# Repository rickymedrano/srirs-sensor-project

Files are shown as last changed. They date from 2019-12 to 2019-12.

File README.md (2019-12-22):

<p align="center">
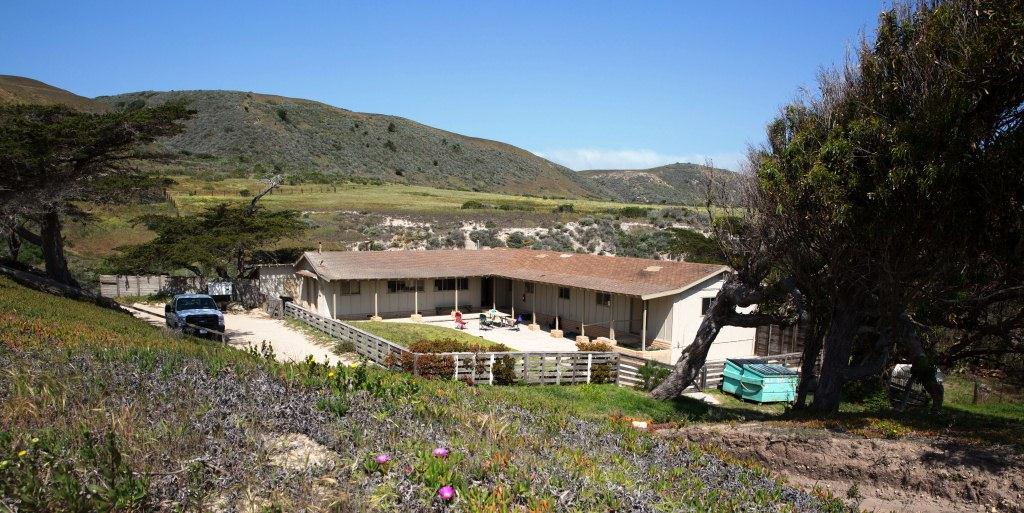
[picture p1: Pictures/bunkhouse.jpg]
Title Picture1
  <kbd></kbd>
</p>
<p align="center">
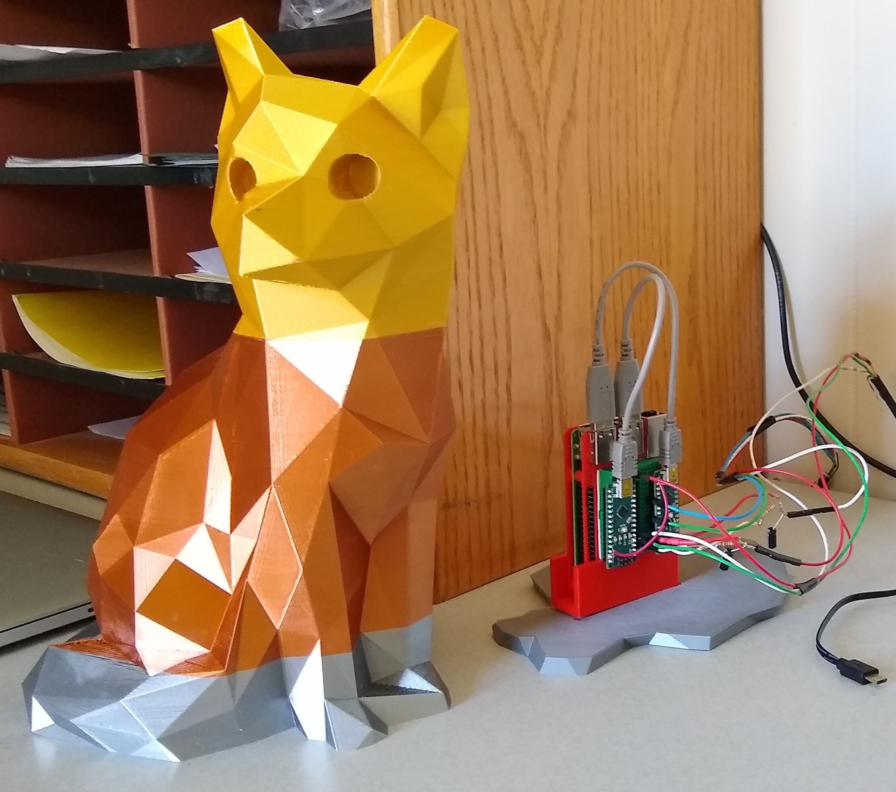
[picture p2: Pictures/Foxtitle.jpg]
Title Picture2
  <kbd></kbd>
</p>

# Overview
This project was a combination Independent Study and Capstone project for undergrad Computer Science students at CSUCI. Not wanting to design another boring app, we decided to tackle a multidisciplinary problem. Santa Rosa Island, off the coast of Southern California, is home to CSUCI's research station. The climate on the island is charaterized by mild Winters and very dry Summers. Combined with severe drought during the past decade, resources on the island are very limited. This project serves a sustainability purpose by allowing research station staff monitor in real time the resource usage of the station. It is a continuation of a project that was initially started in Dr. Wood's UNIV 492 Sustainability in Campus Infrastructure course. 

The project uses a Raspberry Pi as the main computer to read in electric and water usage, then uploads that data to an online database in the cloud. This data is now accessible on the mainland to be viewed graphically. Research station staff can now see how much and when resource usage happens and make sustainable decisions going forward. This project was then tidied up and placed into a 3D printed Island Fox, which is native to the island. 

### Experience Gained ###
* Python
* Arduino (C++)
* Microcontrollers
  * Arduino Uno & Nano
  * Analog to Digital Converter (ADC)
  * Interrupts 
  * Digital and Analog pin inputs and outputs
  * Power requirements via 5V Logic
* Electrical parameters - voltage, amperage, mains electricity, sampling, voltage dividers, resistors, capacitors
* Cloud computing: AWS
* 3D Printing and modeling: Tinkercad
* Database creation and connection, MySQL
* Project Management: Trello
* Raspbian (Linux)
  * systemd - services
  * Navigating the terminal and using bash commands
* Soldering and crimping dupont connections
* Plot.ly, Grafana, Chart-Studio, WordPress

### Program and Code Prerequisites
- Python 3 with mysql connector library
- Arduino IDE with EmonLib library
- Raspbian (we used Stretch, but Buster will work too)
- MySQL database, either locally or in the cloud. We used a MySQL RDS on AWS with their free-tier option. 
- If you want to graph the data you can use a website like Grafana and connect your database, or you can use Plotly's Chart-Studio.
- VNC on Raspbian if you want to connect to your Pi remotely.

### Hardware Prerequisites
You will need a 3D Printer if you want to print the model.
You will need a soldering iron with solder and extra wire as well. 
Here is a list of materials used in the project:

| Item  | Quantity |
| --- | --- |
| <a href="https://www.amazon.com/gp/product/B01N1LBMPG">Arduino Nano</a> | 2 |
| <a href="https://www.amazon.com/gp/product/B07BDR5PDW">Raspberry Pi 3B+</a>  | 1 |
| <a href="https://www.amazon.com/gp/product/B00MARDJZ4">Raspberry Pi Power Supply</a>  | 1 |
| <a href="https://www.amazon.com/gp/product/B073JWXGNT">32GB SD Card</a>  | 1 |
| <a href="https://www.amazon.com/gp/product/B01KKE602W">Mini Breadboard</a>  | 1 |
| <a href="https://www.amazon.com/gp/product/B003WV5DME">6'' USB to Mini USB Cable</a>  | 2 |
| <a href="https://www.amazon.com/gp/product/B01N1LBMPG">Split Core Transformer</a> | 2 |
| <a href="https://www.amazon.com/gp/product/B00X5KHD66">YF-G1 Flowmeter</a> | 2 |
| 10k Resistor | 4 |
| 10uF Capacitor | 2 |

### Getting Started
* I suggest you start here in order to understand how a CT sensor works and how the EmonLib library works https://learn.openenergymonitor.org/electricity-monitoring/ct-sensors/introduction
* You can read about systemd here https://www.raspberrypi.org/documentation/linux/usage/systemd.md
* Electrical
  * This project involves working with mains power and is therefore very dangerous. If you feel even slightly uncomfortable interacting with your breaker box, get the help of an Electrician to hook up the CT sensors. 
  * This project required two CT sensors since there were two main hot lines at the research station but most likely you'll only need 1 CT sensor if you're trying to implement this in a house.
* Water
  * Installing the flowmeter will probably require the help of a Plumber. It requires you shutting off the water main line and then installing the flowmeter inline which involves cutting pipe and testing for leaks. 
  * Your flowmeter will require a certain calibration factor to be set in the code. My calibration is most likely different than yours so you will need to test it yourself. For example, once your flowmeter is installed, you can turn on the facet and fill up a gallon jug then reference back to what the sensor is outputting, and make changes accordingly. 
* Create a free-tier AWS account and create a MySQL database https://aws.amazon.com/rds/free/

### Hardware Setup
* Water
  * Once you've installed your flowmeter, you'll need to hook it up to the Arduino Nano. There are 3 wires, 1 goes to 5V, 1 goes to Ground, 1 goes to digital pin 2 which is the interrupt pin on the Nano. We <a href="https://forum.arduino.cc/index.php?topic=8548.0" target="_blank">read</a> it was suggested to put a 10k resistor, to act as a pull up, between pin 2 and 5V but we tested this with and without the resistor and didn't notice a difference. 
  * Here is what ours looks like hooked up. Note, due to the size constraints of the breadboard, we routed the 5V connection to the other side of the breadboard, as seen by the second red wire.
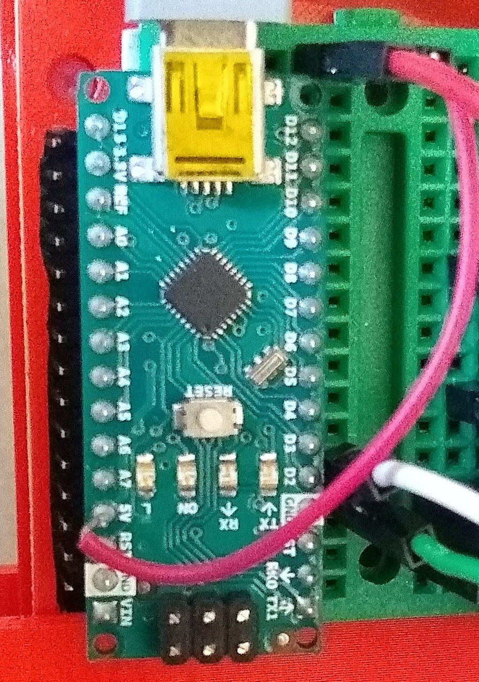
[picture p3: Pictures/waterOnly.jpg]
Water Wiring
  * 
 * Electric
   * We followed the circuit built <a href="https://learn.openenergymonitor.org/electricity-monitoring/ct-sensors/how-to-build-an-arduino-energy-monitor-measuring-current-only" target="_blank">here</a> but adapted it to be used with 2 CT sensors instead of 1. This was how we **initially**  wired up and tested with a breadboard. This set up used burden resistors and shared a 10uF capacitor to act as a low-pass filter:
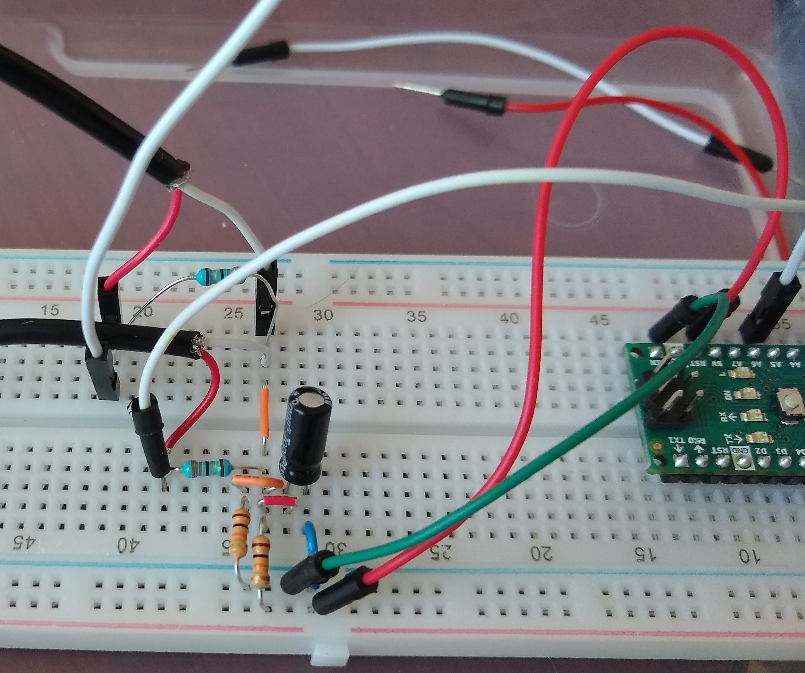
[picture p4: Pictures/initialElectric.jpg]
Initial Electric Wiring
   * 
   * We realized the CTs we had purchased, the ones linked above, had burden resistors built in. We therefore got rid of the burden resistors and added an extra 10uF capacitor that way each sensor got their own. Therefore, the final project had 2 voltage dividers, consisting of 4 10k resistors, and 2 10uF capacitors. In the picture below you can see how we soldered them together and added dupont connections. Note, one of the resistors is hidden under the shrink tubing.
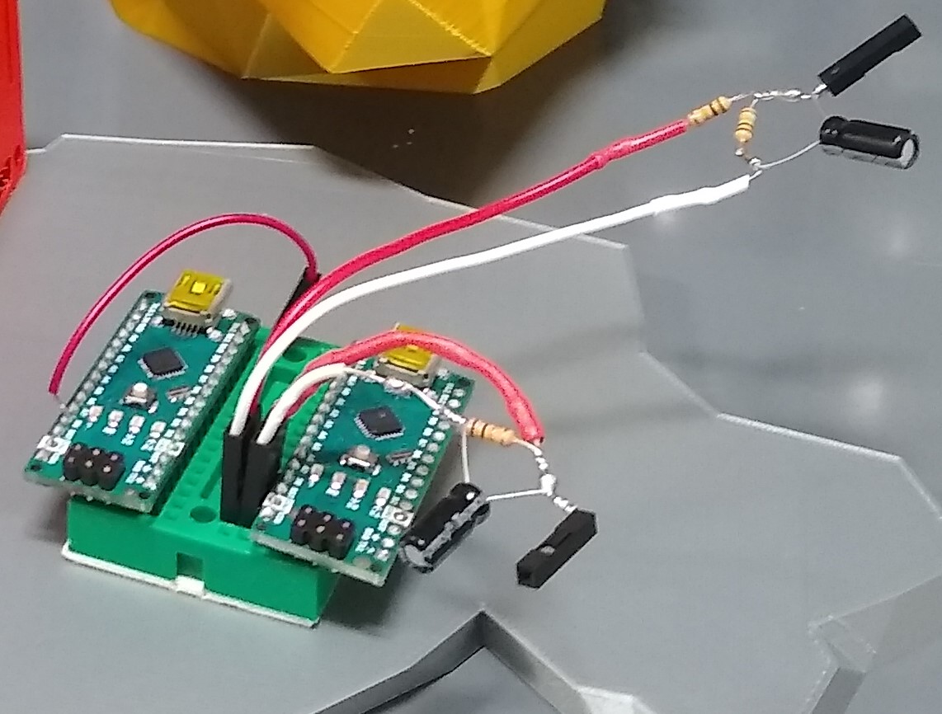
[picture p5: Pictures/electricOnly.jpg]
Electric Wiring
   * 

### The Code
* Python
  * The python scripts "powerRosa.py" and "waterRosa.py" pretty much do the exact same thing, except they upload to different tables in the database
  * Replace the endpoint address, username, and password with your own from the AWS RDS. 
  * It's better practice to save your credentails into environment variables instead of hard coding them in like we did. It worked for us as it was only a school project and the database has been moved already.
  * The reason the script starts with 
  ``` time.sleep(300) ``` is so the router had enough time to connect to the internet everytime the power came back on in the research station. If no internet connection was available, the script would exit when attempting to connect to the database. 
  * The line with ```serial.Serial('/dev/ttyUSB0',9600,timeout=1)``` will need to be modified depending how Raspbian reads in your Arduino Nano on the USB port. Somtimes it will be ACM0USB instead of ttyUSB0 or something entirely different. You can try in the terminal ```dmesg``` or ```dmesg | grep "tty"``` to verify.
* Arduino (C++)
  * Water
    * For water readings, use "yfg1Working.ino". 
    * The code is set up to take readings in mL every second, sum this over 1 minute, before outputting to the serial port, where it is ready by "waterRosa.py". 
    * Manipulate the code based on your temporal needs. I left commented print statements to assist. In your final iteration make sure you only have one print statement in the code as the Python script is only parsing 1 value over the serial port.
    * Don't use ```Serial.println()``` as it puts a new line character at the end of the output. Instead stick with ```Serial.print()``` unless you want to handle the new line character on the Python script side.
  * Electric
    * This code is meant if you're using two CT sensors. If you only plan to use 1 CT sensor, just remove the emon2 object and associates lines.
    * Like the water sensor code, this will read mA per second, sum it over 1 minute, and then output to the Serial port. 
* Raspbian
  * For the purpose of this project, our scripts needed to be started automatically anytime the Raspberry Pi started up. There are a couple options available for gettings scripts to start automatically, like with a cron job. Since systemd was introduced with Raspbian Jessie, we decided to use it. This involves creating a .service file for each script, then using systemctl to manage those service files. Here is a picture of both our services, along with their locations, and where they point to in starting our Python scripts:
  <p align="center">
    <img src="./Pictures/services.png" alt="Water Wiring" width="600"/>
  </p> 
  
* Use ```sudo systemctl start myservice.service``` to start the service, ```sudo systemctl stop myservice.service``` to stop it. Finally use ```sudo systemctl enable myservice.service``` so that it starts up on every reboot. ```sudo systemctl status myservice.service``` is also helpful in making sure things are running properly.  
* We spent much time tuning these services as they rely on many factors. If you find your service stops running, use ```journalctl``` to debug. A big issue for us was we were running the service files  with ```User=root``` but for some reason root couldnt access our mysql.connector library. Changing it to ```User=pi``` solved that issue. 

### 3D Printing
I've included all the .stl files if you want to print the fox. 
* The body requires supports and should be printed no more than 0.15mm per layer. There is some artifacting where the top of the tail meets the body in the front of the model. 
* Post processing is needed on the body model where you have to cut out the hole near the tail to feed the wires through
* The head should be printed around 15%, anymore will make it top heavy
* The bracket should be printed around 15% so it's easy to put a screw through
* The base should be printed around 15% for the same reason as the bracket
* All the models were printed on a Prusa MK3S. I have no settings recommendations on other types of printers.

Once all is printed, screw the bracket onto the base. Hollow out the hole on the body where the power and sensor wires come in. Use super glue to attach the head to the body. 

### Graph
Here is our plotted data, which shows resource usage each time a group went out to the research station. On Grafana, the graph is interactable, where you can zoom in and see usage down to each minute. 
  <p align="center">
    <img src="./Pictures/grafana.png" alt="Water Wiring" width="600" style="border-radius:10%"/>
  </p> 

### Ideas to Build On
* Use a Rasbperry Pi Zero W, hooked up to a Magic Mirror or monitor, that displays energy usage in real time. Place on wall in the research station so visitors can see how much electricty and water they are using.
* Use an Arduino Nano with wifi option to send electric data wireless from the back of the breaker box, instead of having to run a line from the breaker box to to Nano. Same goes for water sensor.
* Write an algorithm that detects anomalies in the data such as leaks or visitors abusing the resources. Use AWS Lambda for this to trigger an email to be sent to appropriate personnel.
* Do this same set up but over at the Lab on the island to measure its water and power usage.
* Hook up more sensors such as temperature, humidity, CO2, etc.

### Authors
Ricky Medrano and Geraldine Salazar-Harms

<img src="./Pictures/RandGCropped.jpg" alt="R&G" width="500">
<img src="./Pictures/RandG2.jpg" alt="R&G1" width="500">

## Acknowledgments
 * Advisors
   * <a href="https://ciapps.csuci.edu/FacultyBiographies/gregory.wood">Dr. Gregory Wood</a> 
   * <a href="https://ciapps.csuci.edu/FacultyBiographies/brian.thoms">Dr. Brian Thoms</a> 
   * <a href="https://ciapps.csuci.edu/FacultyBiographies/michael.soltys">Dr. Michael Soltys</a>
 * Santa Rosa Island Research Station
   * Russ Bradley
   * Aspen Coty
   * Robyn Shea
   * Joe Forrest
 * Judith Stapleman Foundation, Edison International, Matthew Hillman Fisher Foundation, Havasi Wilderness Foundation, and Keith Wescott for supporting transportation and lodging fees
 * Channel Islands National Park (CHIS NPS)
## Extra Pictures
Pictures tiled with MATLAB 
```
out = imtile({'1.jpg','2.jpg','3.jpg','4.jpg'}, 'GridSize',[2 2], 'BorderSize', 25);
imshow(out);
```

**Water**
<p align="center">
    <img src="./Pictures/waterTiled.png" alt="Water Tiled"/>
</p>
  
 **Electricity**
 <p align="center">
    <img src="./Pictures/electricTiled.png" alt="Water Tiled"/>
</p>
  
 **Fox**
 <p align="center">
    <img src="./Pictures/foxTiled.png" alt="Water Tiled"/>
 </p>
 
**Ricky and Joe at the Breaker Box**
 <p align="center">
    <img src="./Pictures/RandJ.jpg" alt="Water Tiled"/>
 </p>

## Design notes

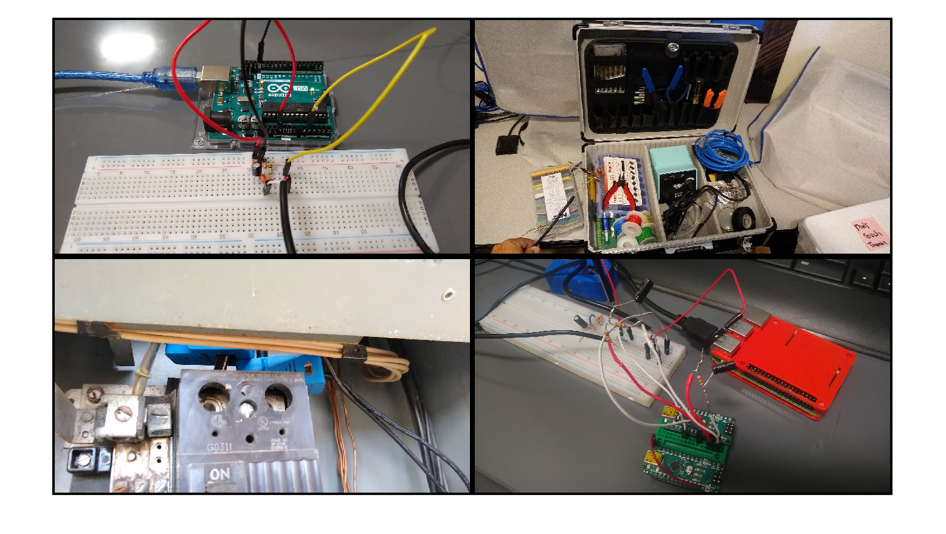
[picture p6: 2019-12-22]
Pictures/electricTiled.png

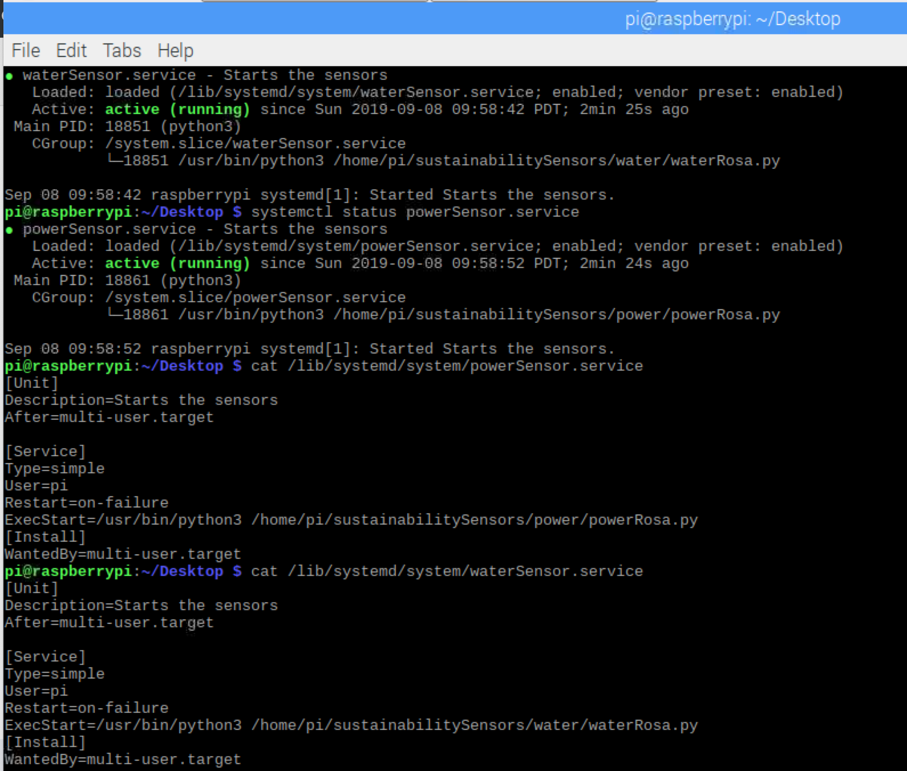
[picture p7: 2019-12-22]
Pictures/services.png

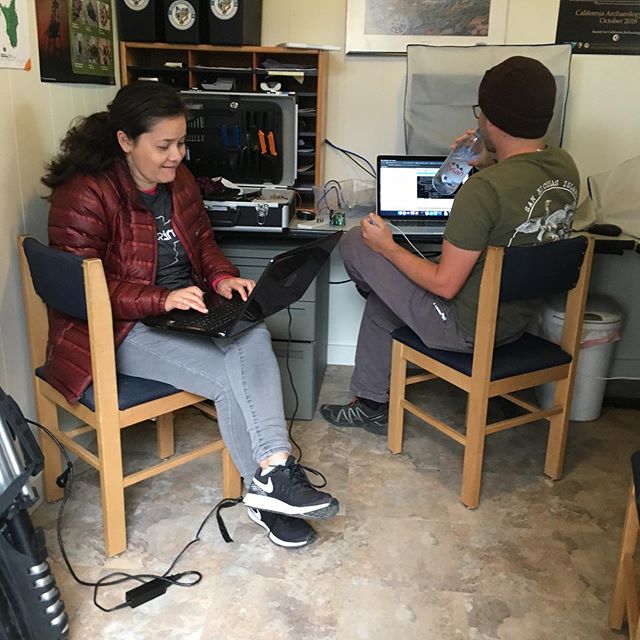
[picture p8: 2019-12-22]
Pictures/RandG1.jpg

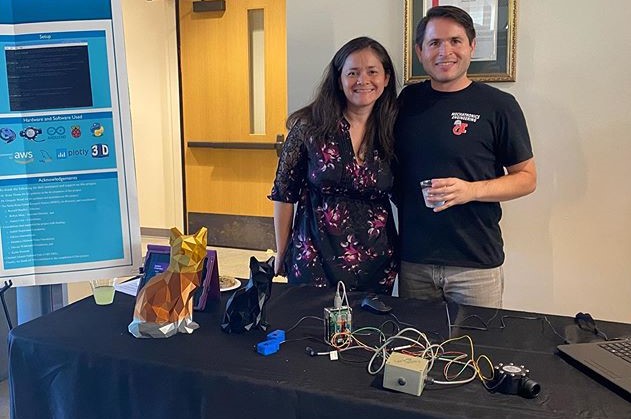
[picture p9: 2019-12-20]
Pictures/RandGCropped.jpg

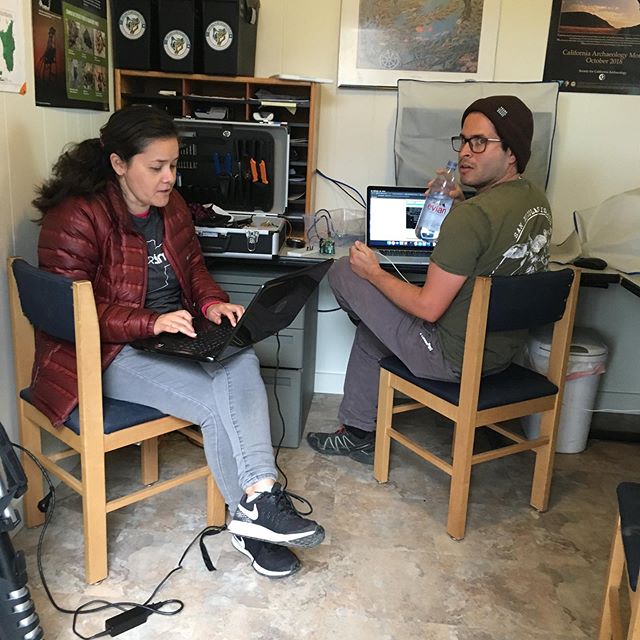
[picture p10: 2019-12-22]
Pictures/RandG2.jpg

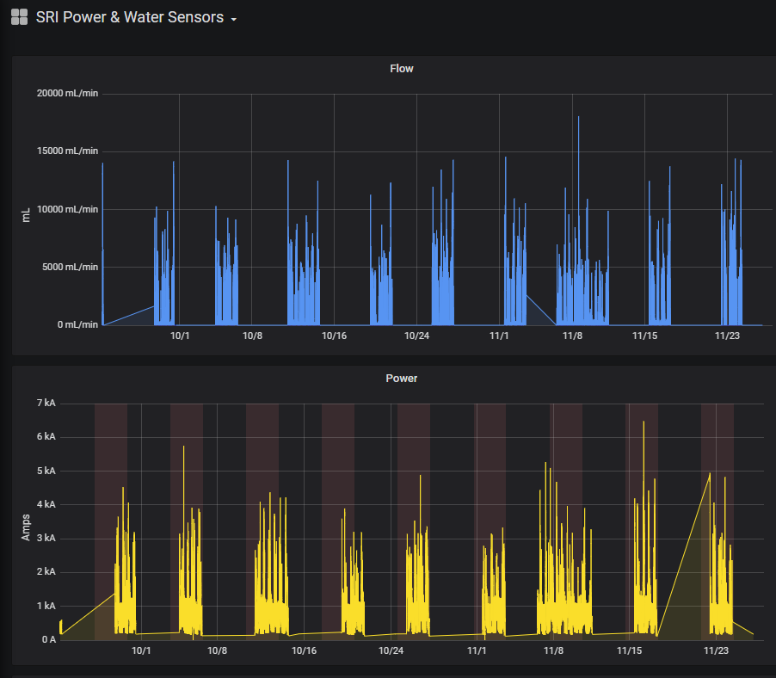
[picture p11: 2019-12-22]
Pictures/grafana.png

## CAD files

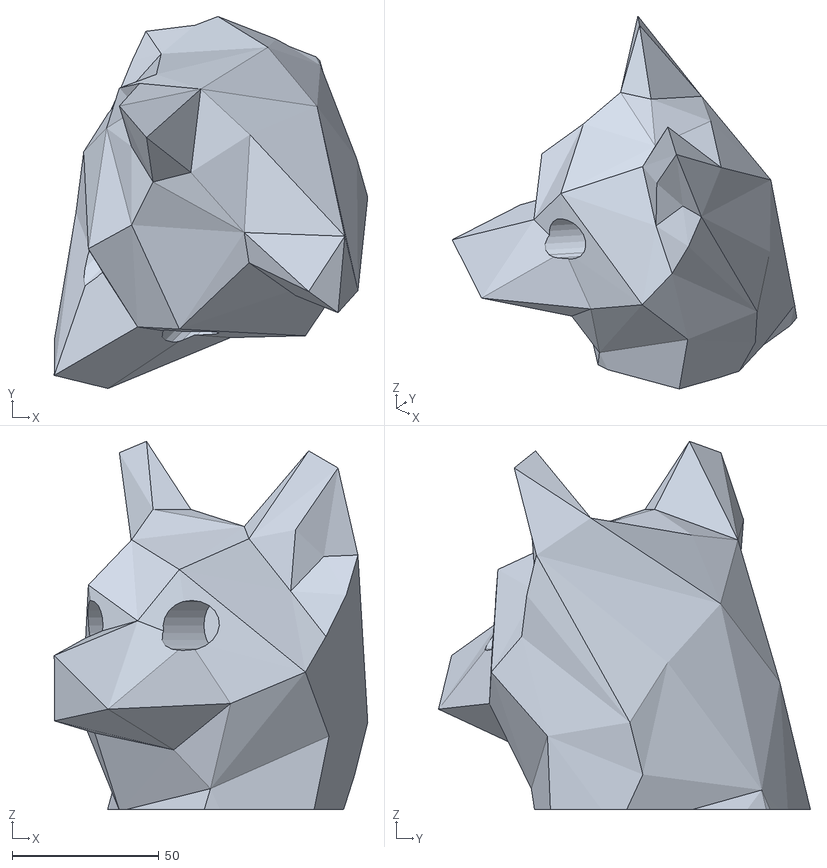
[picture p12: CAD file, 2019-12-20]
3DModels/foxhead.stl
107.0 x 126.9 x 125.7

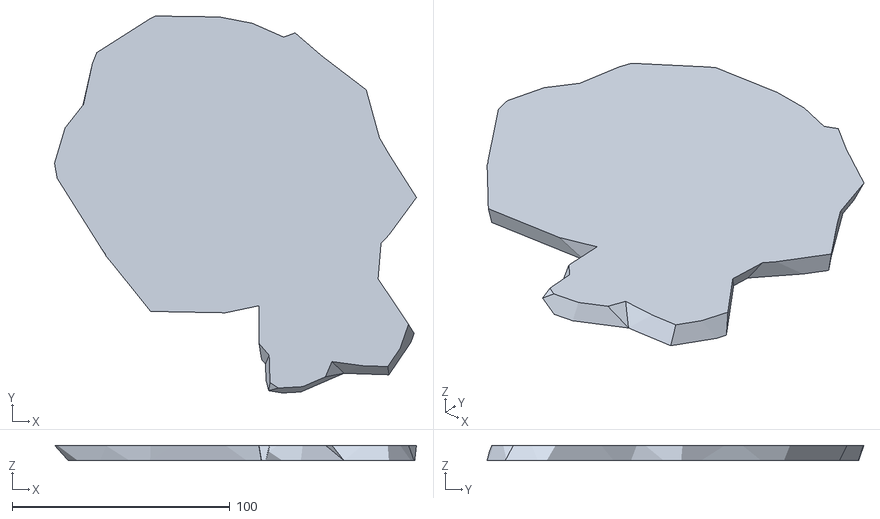
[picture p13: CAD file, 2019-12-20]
3DModels/foxbase.stl
166.1 x 173.0 x 7.10

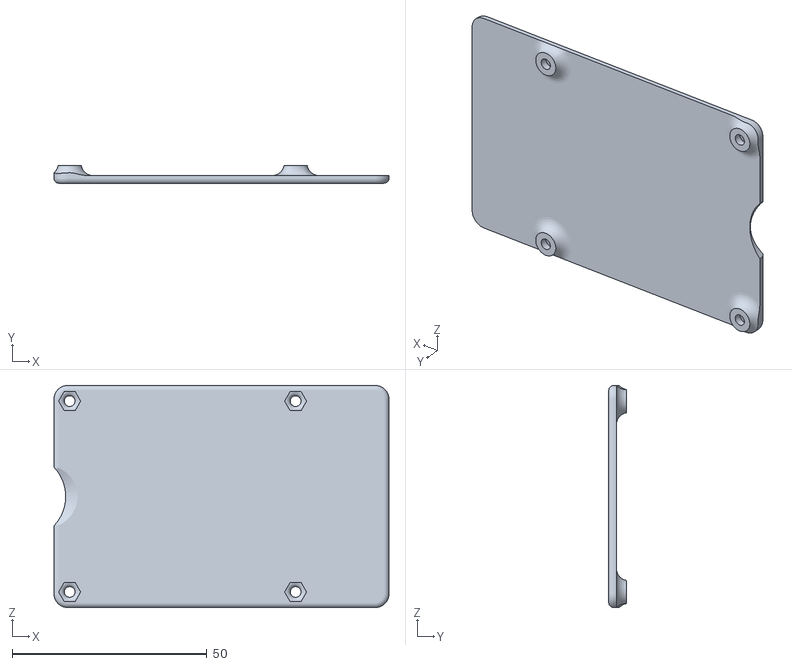
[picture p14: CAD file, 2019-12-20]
3DModels/PiCaseBottom.stl
86.0 x 4.50 x 57.0

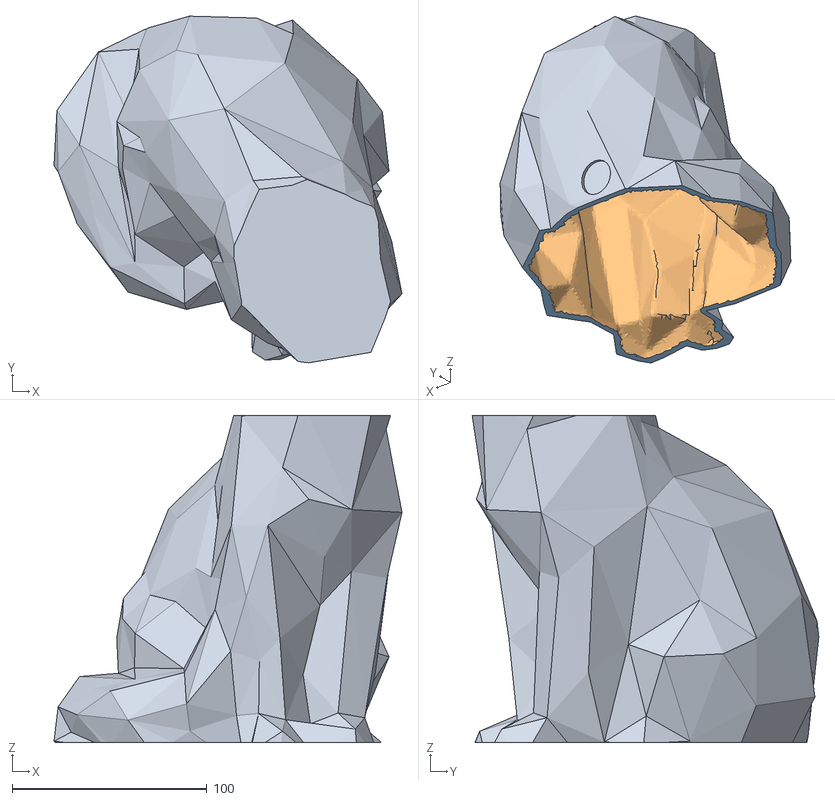
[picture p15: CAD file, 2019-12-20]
3DModels/foxbody.obj
178.7 x 178.0 x 167.9
mmGroup0
mmGroup1
mmGroup3

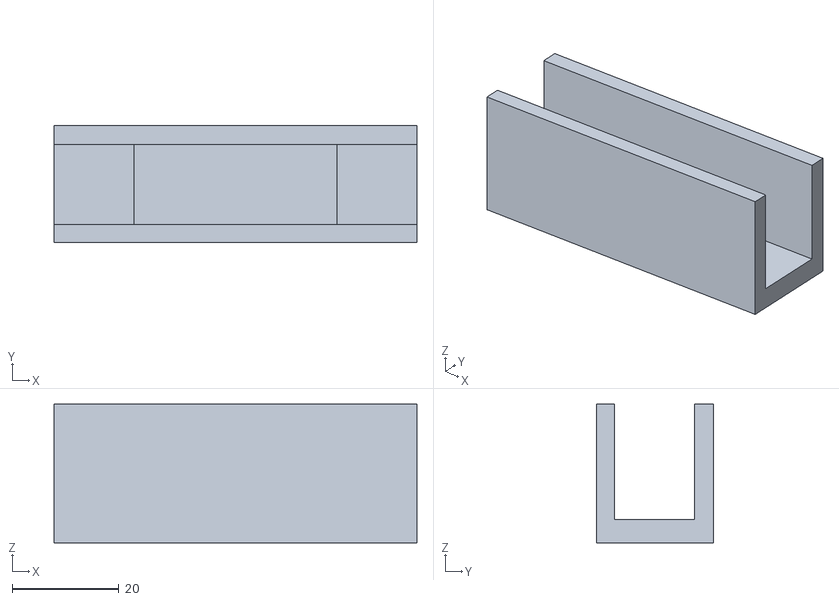
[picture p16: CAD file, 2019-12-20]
3DModels/PiBracket.stl
68.0 x 22.0 x 26.0

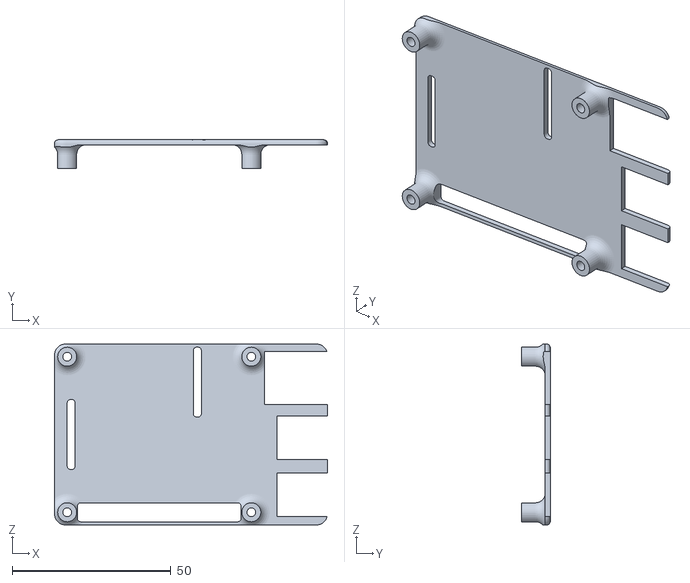
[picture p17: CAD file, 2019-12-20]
3DModels/PiCaseTop.stl
86.0 x 9.00 x 57.0

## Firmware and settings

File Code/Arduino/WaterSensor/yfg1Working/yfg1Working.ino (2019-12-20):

/* 
Connect Vcc and Gnd of sensor to arduino, and the 
signal line to arduino digital pin 2.
*/

byte sensorInterrupt = 0;  // 0 = digital pin 2
byte sensorPin       = 2;

// The hall-effect flow sensor outputs approximately 4.5 pulses per second per
// litre/minute of flow.
float calibrationFactor = 1.25;

volatile byte pulseCount;  

float flowRate;
unsigned int flowMilliLitres;
unsigned long totalMilliLitres;
unsigned int  mLperMinute;
unsigned long oldTime;
unsigned long oldTime2;

void setup()
{
  // Initialize a serial connection for reporting values to the host
  Serial.begin(9600);
 
  pinMode(sensorPin, INPUT);
  digitalWrite(sensorPin, LOW);

  pulseCount        = 0;
  flowRate          = 0.0;
  flowMilliLitres   = 0;
  totalMilliLitres  = 0;
  mLperMinute       = 0;
  oldTime           = 0;
  oldTime2          = 0;
  // The Hall-effect sensor is connected to pin 2 which uses interrupt 1.
  // Configured to trigger on a RISING state change (transition from LOW
  // state to HIGH state)
  attachInterrupt(sensorInterrupt, pulseCounter, RISING);
}
void loop()
{
   if((millis() - oldTime) > 1000)    // Only process counters once per second
  { 
    // Disable the interrupt while calculating flow rate and sending the value to
    // the host
    detachInterrupt(sensorInterrupt);
        
    // Because this loop may not complete in exactly 1 second intervals we calculate
    // the number of milliseconds that have passed since the last execution and use
    // that to scale the output. We also apply the calibrationFactor to scale the output
    // based on the number of pulses per second per units of measure (litres/minute in
    // this case) coming from the sensor.
    flowRate = ((1000.0 / (millis() - oldTime)) * pulseCount) / calibrationFactor;
    
    // Note the time this processing pass was executed. Note that because we've
    // disabled interrupts the millis() function won't actually be incrementing right
    // at this point, but it will still return the value it was set to just before
    // interrupts went away.
    oldTime = millis();
    
    // Divide the flow rate in litres/minute by 60 to determine how many litres have
    // passed through the sensor in this 1 second interval, then multiply by 1000 to
    // convert to millilitres.
    flowMilliLitres = (flowRate / 60) * 1000;
    
    // Add the millilitres passed in this second to the cumulative total
    totalMilliLitres += flowMilliLitres;
    mLperMinute += flowMilliLitres;  
    unsigned int frac;
    
    // Print the flow rate for this second in litres / minute
//    Serial.print("Flow rate: ");
//    Serial.print(int(flowRate));  // Print the integer part of the variable
//    Serial.print("L/min");
//    Serial.print("\t");       // Print tab space
    // Print the cumulative total of litres flowed since starting
//    Serial.print("Output Liquid Quantity: ");        
//    Serial.print(totalMilliLitres);
//    Serial.println("mL"); 
    // Reset the pulse counter so we can start incrementing again
    pulseCount = 0;
    
    // Enable the interrupt again now that we've finished sending output
    attachInterrupt(sensorInterrupt, pulseCounter, RISING);
  }
     if((millis() - oldTime2) > 60000) {
    //Serial.print("its been 5 seconds, total flow in the past minute: ");
    Serial.print(mLperMinute);
    mLperMinute = 0;
    oldTime2 = millis();
   }
}
/*
Insterrupt Service Routine
 */
void pulseCounter()
{
  // Increment the pulse counter
  pulseCount++;
}

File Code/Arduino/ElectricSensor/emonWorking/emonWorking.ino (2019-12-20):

// EmonLibrary examples openenergymonitor.org, Licence GNU GPL V3

#include "EmonLib.h"                   // Include Emon Library
EnergyMonitor emon1;                   // CT1
EnergyMonitor emon2;                   // CT2
unsigned long oldTime;
float powerPerMin;
float currPerMin; 
float totalIrms;
void setup()
{ 
  Serial.begin(9600); 
  powerPerMin = 0;
  currPerMin = 0;
  emon1.current(1, 60);             // CT1: input pin, number of max amps the CT can measure
  emon2.current(5, 60);             // CT2: same as CT1
}

void loop()
{
  double Irms1 = emon1.calcIrms(1480);  //1480 is the sampling rate, can also use 1676 //kitchen
  double Irms2 = emon2.calcIrms(1480); //
  //temp code for quickly seeing serial output
//  Serial.print("Irms1: ");
//  Serial.println(Irms1);
//  Serial.print("Irms2: ");
//  Serial.println(Irms2);
  totalIrms += (Irms1 + Irms2);
  //Serial.println(totalIrms);
  //currPerMin += totalIrms;
  //currPerMin += Irms1;
  //temp code end
  if((millis() - oldTime) > 60000) {
      //Serial.println(currPerMin);  // times by 2 to calibrate it with annmeter (old line when only using 1 CT)
      Serial.print(totalIrms);
      //powerPerMin = currPerMin*123.7;
      //Serial.println(powerPerMin);    // Apparent power
      //currPerMin = 0;
      totalIrms = 0;
      oldTime = millis();
  }
}
